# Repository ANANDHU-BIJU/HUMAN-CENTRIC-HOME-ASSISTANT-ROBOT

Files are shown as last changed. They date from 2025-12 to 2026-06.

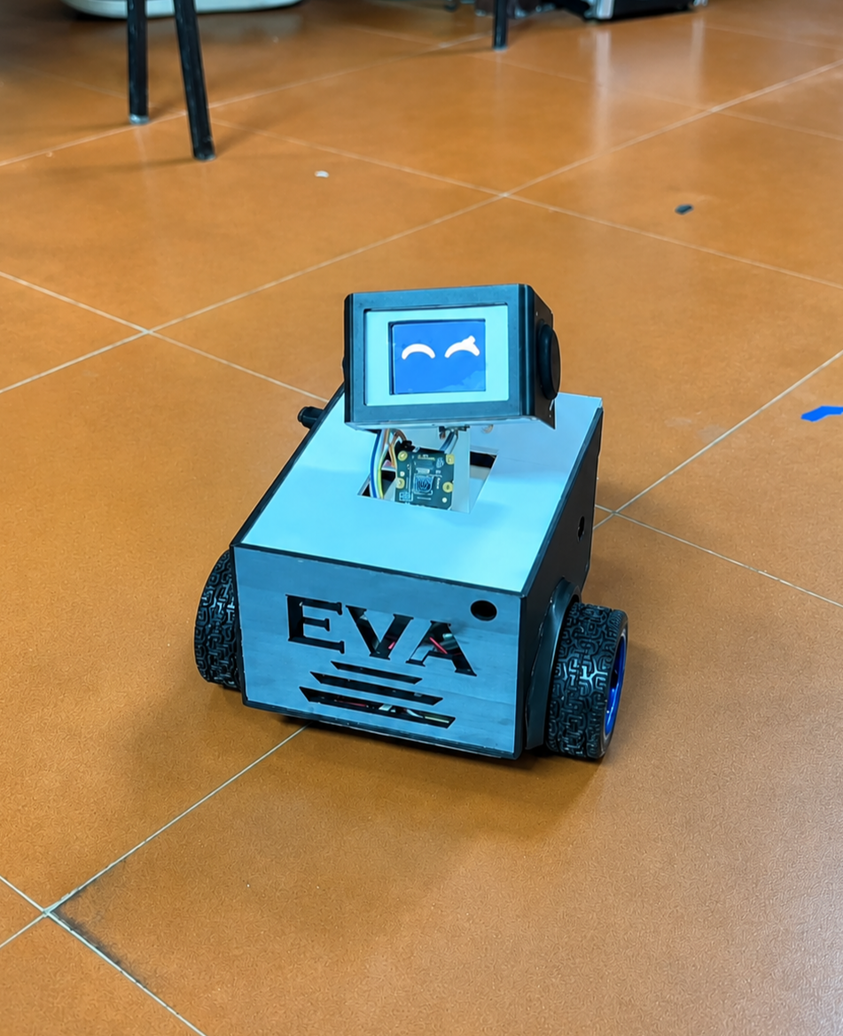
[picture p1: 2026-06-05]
HUMAN_CENTRIC_EMBODIED_HOME_ASSISTANT.png

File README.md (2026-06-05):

# EVA — Human Centered Embodied Home Assistant 🤖

> Voice-activated home assistant robot with face recognition, radar presence detection,
> expressive head movement, and smart home automation.
> 
> 🥇 **First Place — INNOVIX, RISE 2026 | FISAT ECE Department**

---

## 🧠 What is EVA?

EVA is a fully functional human-centric home assistant robot built on **Raspberry Pi 2 + ESP32**,
designed to recognize users, navigate to them, and assist through natural voice interaction.

Unlike conventional voice assistants, EVA physically moves to the user, verifies identity
through face recognition, and responds with expressive animations — making interaction
more natural and personal.

---

## ⚙️ System Architecture

```
┌─────────────────────────────────────────┐
│         RASPBERRY PI 2 MODEL B          │
│  Face Recognition · Voice · Navigation  │
│  Intent Engine · Flask Web UI · Groq AI │
└──────────────┬──────────────────────────┘
               │ HTTP (WiFi)
┌──────────────▼──────────────────────────┐
│              ESP32 WROOM-32             │
│  Motors · Servos · TFT · Radar · Face  │
└──────────────────────────────────────────┘
               │ HTTP (WiFi)
┌──────────────▼──────────────────────────┐
│            ESP8266 NodeMCU              │
│     Garden Relay · Light Control        │
└──────────────────────────────────────────┘
```

---

## 🔧 Features

| Feature | Details |
|---|---|
| 🎙️ Wake Word | Porcupine — "Hey Eva" |
| 👁️ Face Recognition | OpenCV — Haar + LBPH |
| 📡 Presence Detection | LD2410 mmWave Radar |
| 😊 Face Display | ST7735R TFT — 6 bitmap expressions |
| 🤖 3-DoF Head | MG90S servos — Yaw · Pitch · Roll |
| 🚗 Navigation | TB6612FNG + N25 gear motors |
| 🏠 Home Automation | ESP8266 relay — pump + lights |
| 🧠 AI Conversation | Groq LLM (Llama 3) |
| 🌐 Web UI | Flask dashboard — auth + controls |
| 🔌 Custom PCB | KiCad 9.0.5 — full system integration |
| 🖨️ Body | 3D printed enclosure (PLA) |

---

## 🛠️ Hardware

- Raspberry Pi 2 Model B
- ESP32 WROOM-32 DevKit
- ESP8266 NodeMCU
- Pi Camera Module V2 (NoIR)
- ST7735R TFT Display
- HLK-LD24 mmWave Radar
- TB6612FNG Motor Driver
- N25 Metal Gear Motors × 2
- MG90S Servo Motors × 3
- PAM8403 Audio Amplifier
- Custom PCB (KiCad 9.0.5)
- 2S Li-ion Battery (7.4V)

---

## 💻 Software Stack

```python
stack = {
    "Pi"      : ["Python 3", "OpenCV", "Porcupine", "Flask",
                 "edge-TTS", "Google STT", "Groq LLM"],
    "ESP32"   : ["Arduino C++", "WebServer", "SPI", "LEDC PWM"],
    "ESP8266" : ["Arduino C++", "ESP8266WebServer"],
    "PCB"     : ["KiCad 9.0.5"],
    "Body"    : ["Fusion 360", "3D Printing (PLA)"],
}
```

---

## 📬 Contact




---

<p align="center"><i>Built with curiosity. Powered by embedded silicon. Driven by the need to build things that actually work.</i></p>

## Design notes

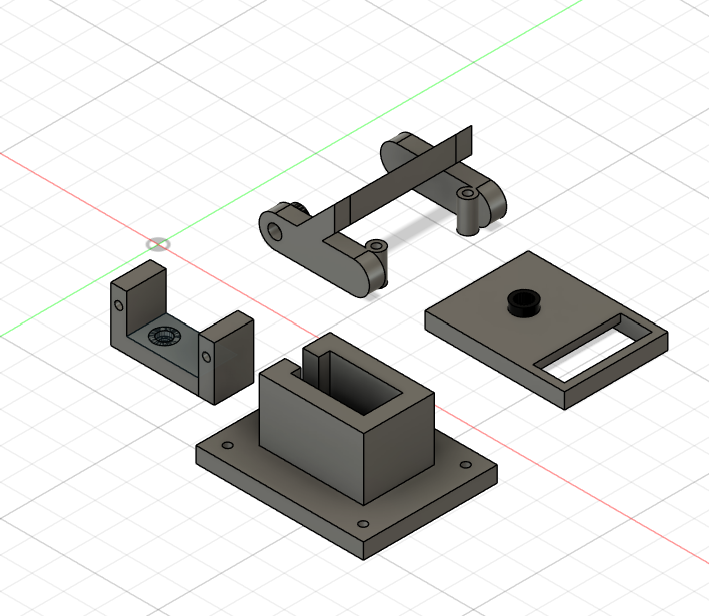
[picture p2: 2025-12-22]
mechanical/renders/exploded_view.png

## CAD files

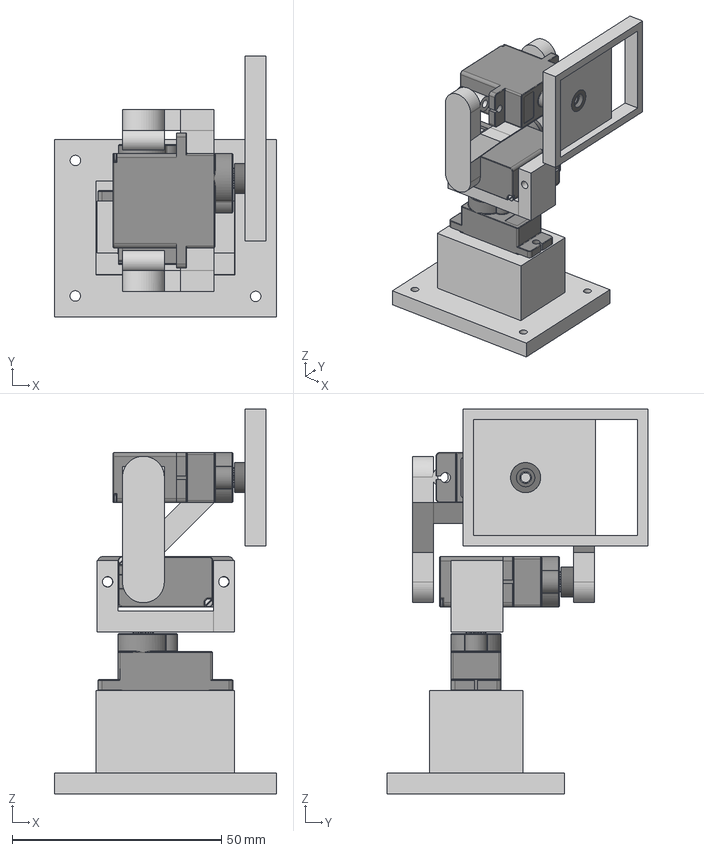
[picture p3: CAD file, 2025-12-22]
mechanical/assembly/head_assembly_v1.step
53.1 x 62.3 x 92.0 mm
Shaft x 3
Horn x 3
Screw x 3

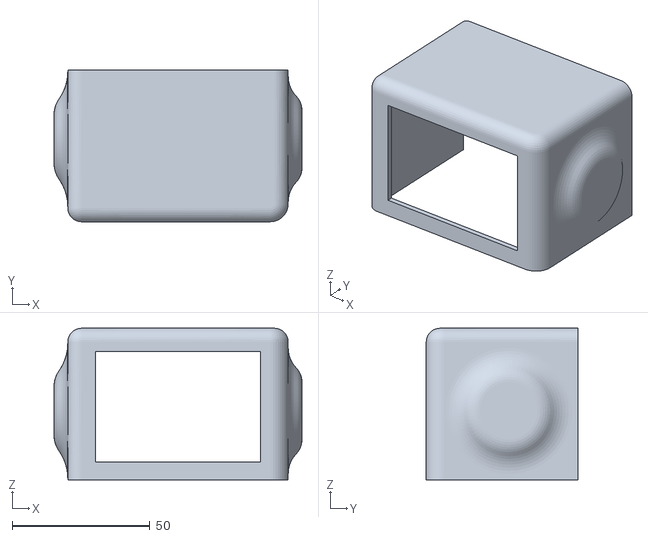
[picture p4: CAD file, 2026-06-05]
mechanical/parts/EVA_HEAD_COVER.stl
90.0 x 55.0 x 55.0

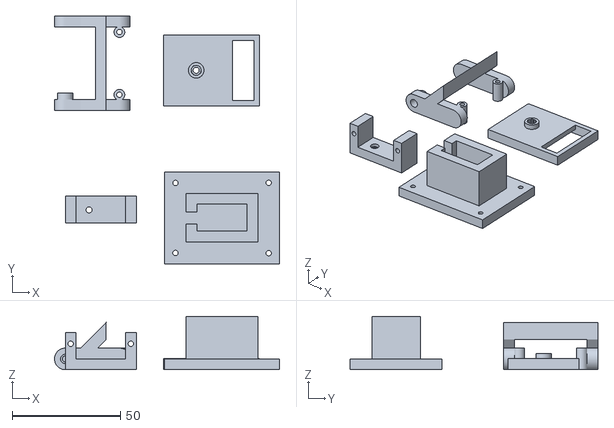
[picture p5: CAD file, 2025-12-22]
mechanical/assembly/exploded_view_v1.stl
104.0 x 114.4 x 24.7

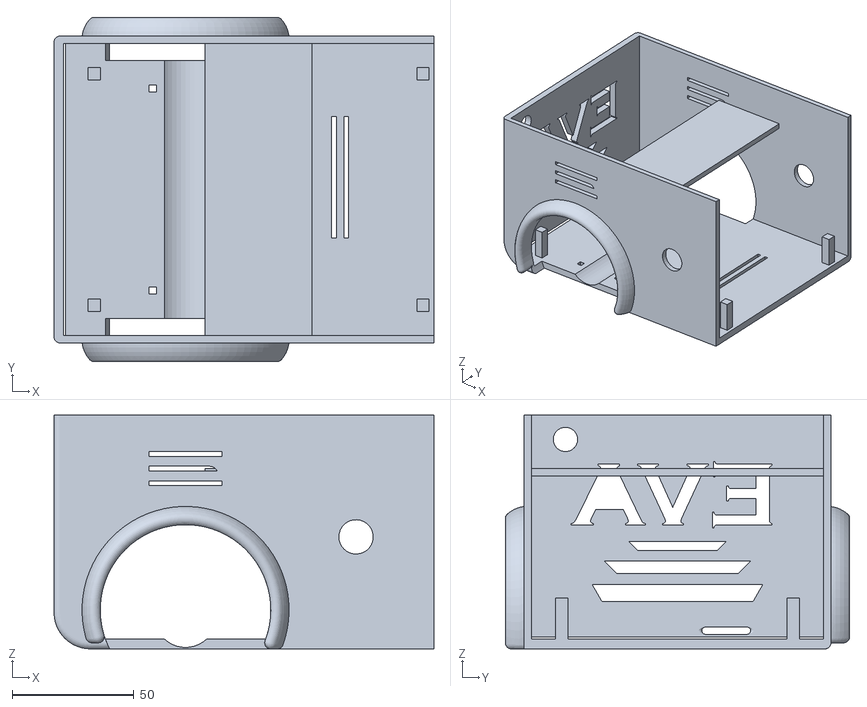
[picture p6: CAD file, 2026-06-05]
mechanical/parts/EVA_BODY.stl
156.0 x 141.4 x 96.0

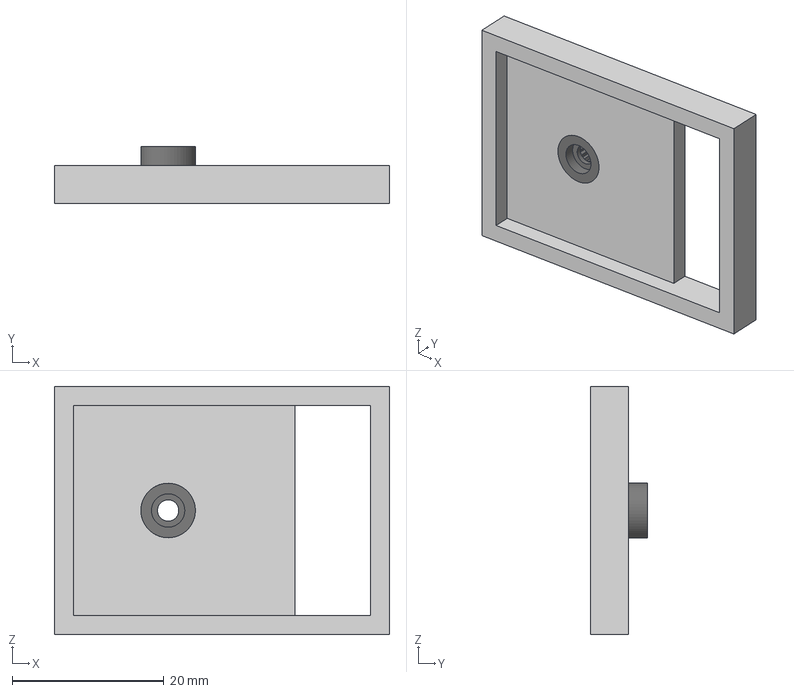
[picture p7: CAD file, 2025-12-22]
mechanical/parts/roll_mount_v1.step
44.2 x 7.50 x 32.8 mm
Shaft
Horn
Screw

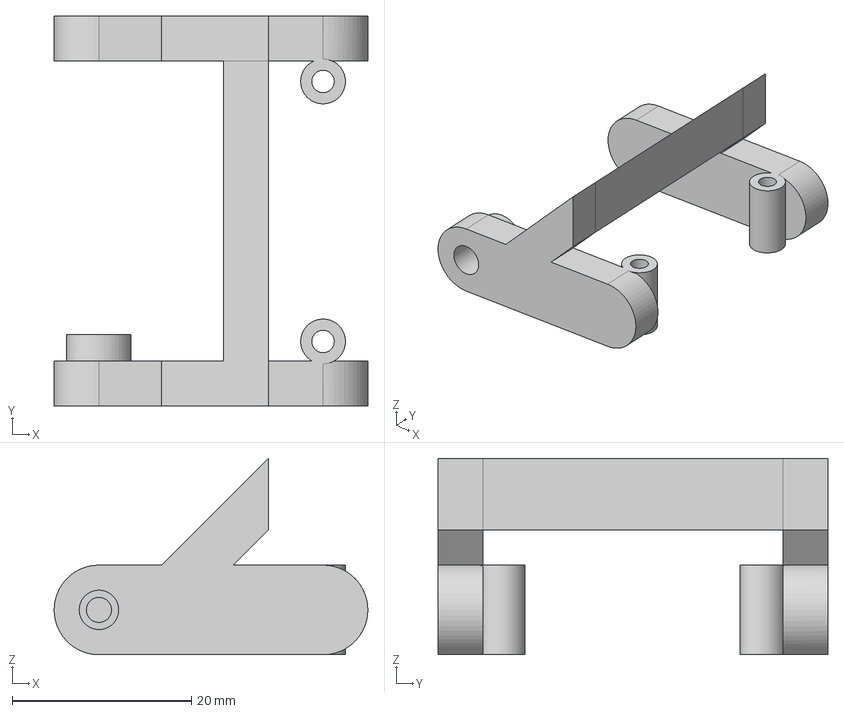
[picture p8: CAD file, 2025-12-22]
mechanical/parts/pitch_mount_v1.step
35.0 x 43.5 x 21.9 mm
Shaft
Horn
Screw

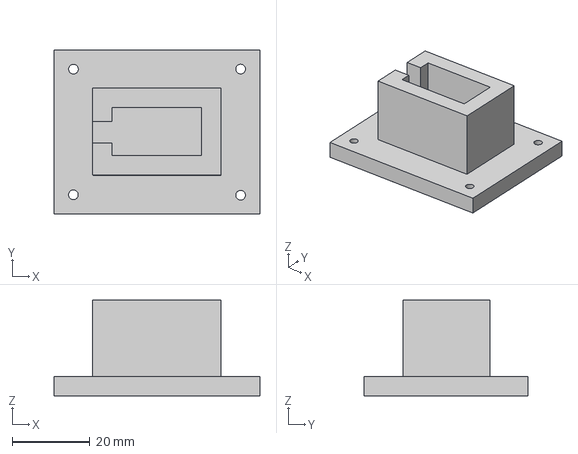
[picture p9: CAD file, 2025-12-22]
mechanical/parts/base_mount_v1.step
53.1 x 42.4 x 24.7 mm

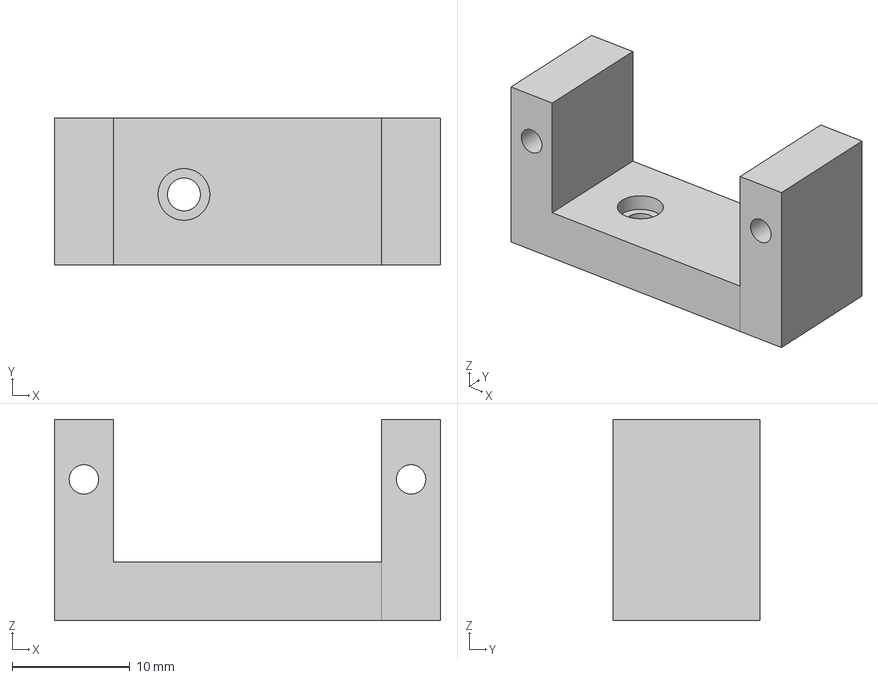
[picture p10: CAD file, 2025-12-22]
mechanical/parts/yaw_mount_v1.step
32.8 x 12.5 x 17.1 mm
Shaft
Horn
Screw

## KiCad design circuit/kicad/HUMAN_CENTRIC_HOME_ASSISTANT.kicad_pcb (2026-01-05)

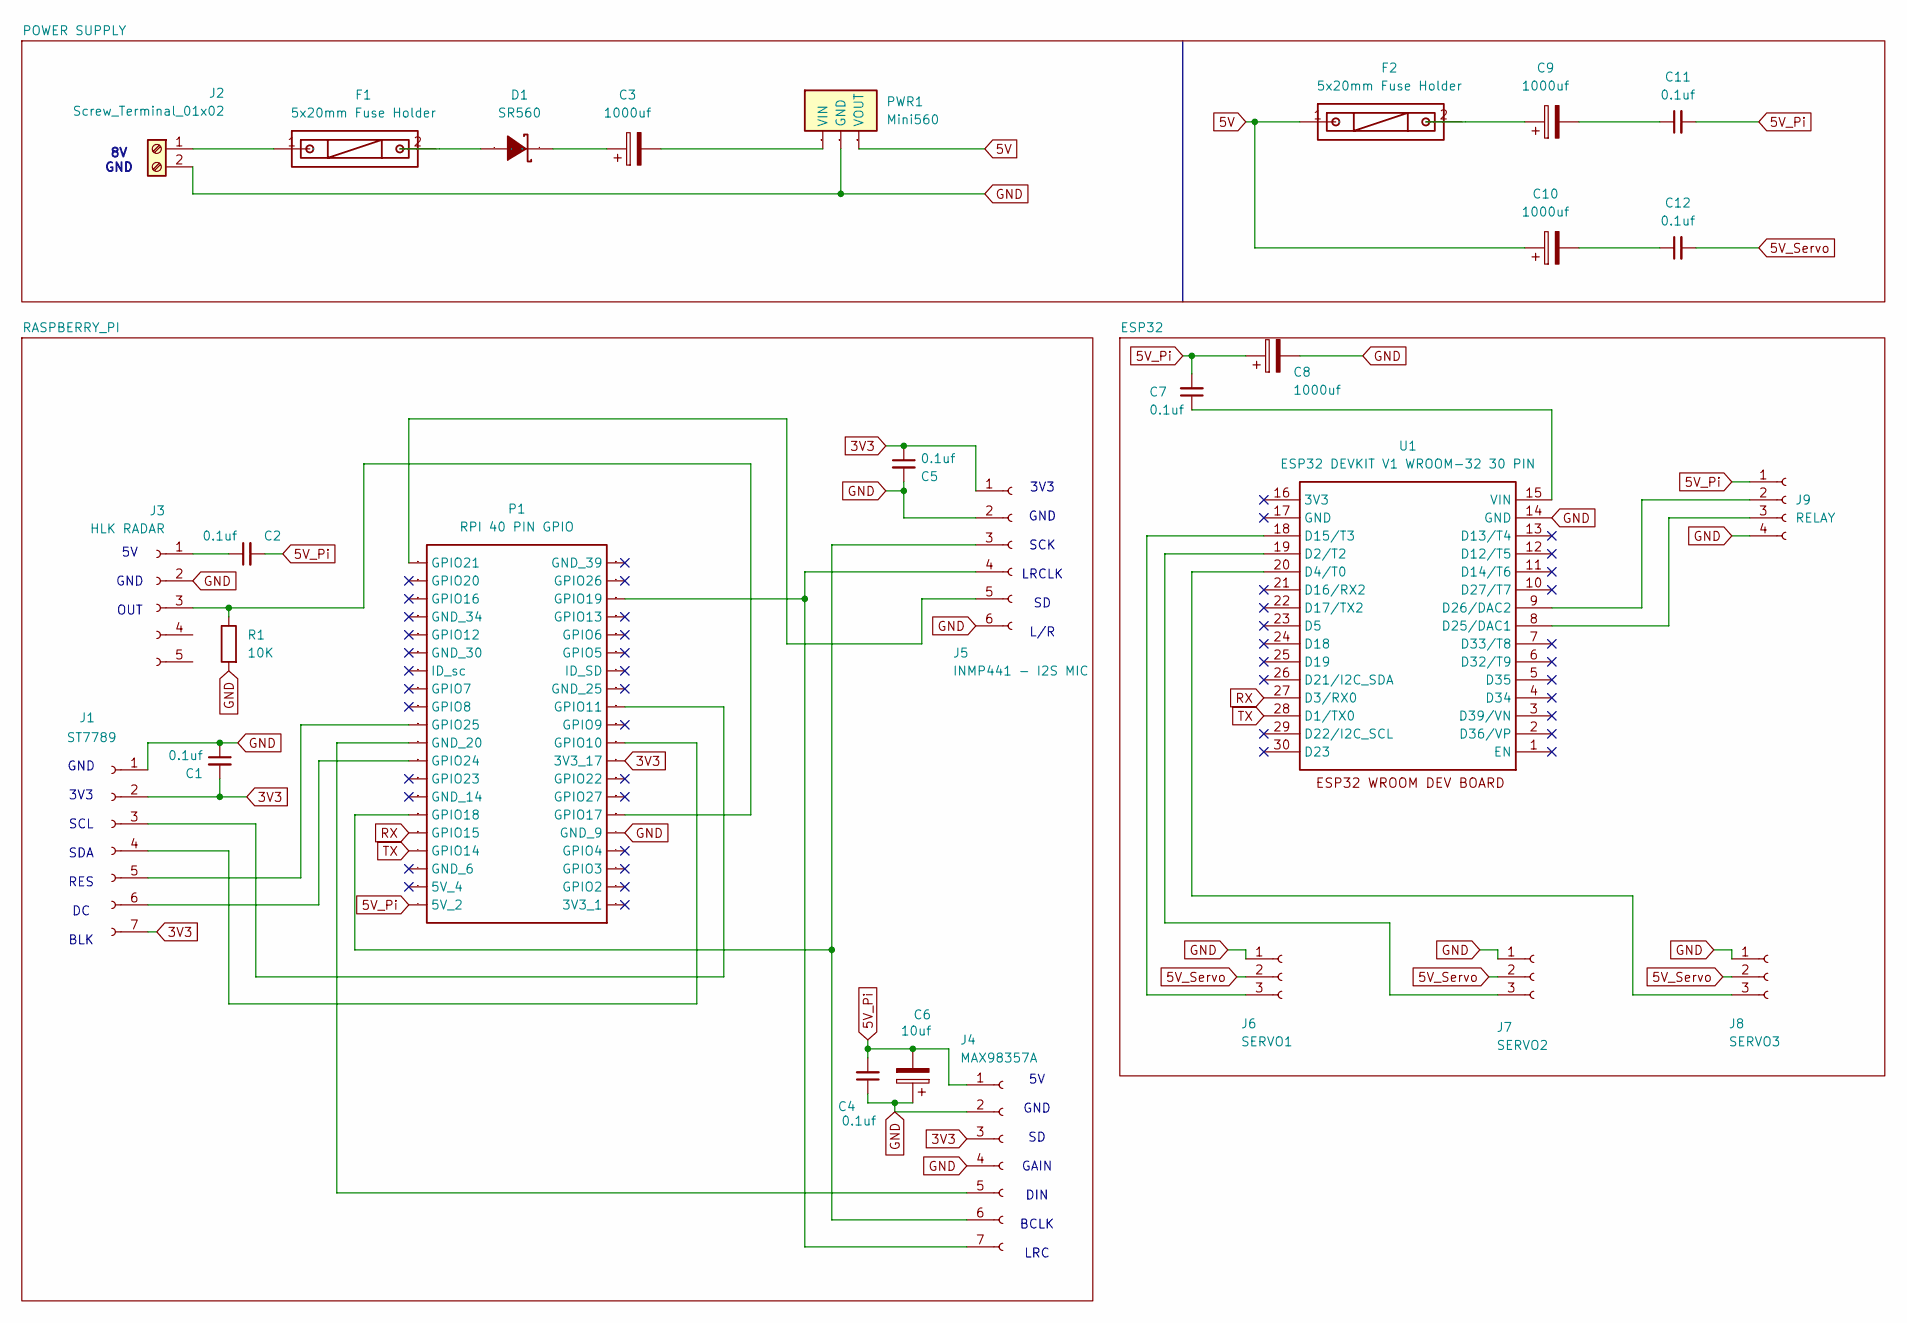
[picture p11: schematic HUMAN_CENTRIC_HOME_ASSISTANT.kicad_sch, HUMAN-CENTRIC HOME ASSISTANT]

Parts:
C1, C2, C4, C5, C7, C11, C12: 0.1uf; C_Disc_D5.0mm_W2.5mm_P5.00mm
C3, C8, C9, C10: 1000uf; CP_Radial_D10.0mm_P5.00mm
C6: 10uf; CP_Radial_D6.3mm_P2.50mm
D1: SR560; SR560 Schottky Barrier Rectifier Diode 5A; Manufacturer Part SR560
F1, F2: 5x20mm Fuse Holder; 5X20-FUSE
J1: ST7789; PINHEADER_1X07_P2.54MM_VERTICAL
J2: Screw_Terminal_01x02; SCREWTERMINAL-5MM-2-DW
J3: HLK RADAR; PINHEADER_1X05_P2.54MM_VERTICAL
J4: MAX98357A; PINHEADER_1X07_P2.54MM_VERTICAL
J5: INMP441 - I2S MIC; CONNECTOR_PINHEADER_2.54MMPINHEADER_1X06_P2.54MM_VERTICAL
J6: SERVO1; CONN-HEADER-STRAIGHT-P2.54MM-1X03
J7: SERVO2; CONN-HEADER-STRAIGHT-P2.54MM-1X03
J8: SERVO3; CONN-HEADER-STRAIGHT-P2.54MM-1X03
J9: RELAY; PINSOCKET_1X04_P2.54MM_VERTICAL
P1: RPI 40 PIN GPIO; 2X20-PIN-HEADER
PWR1: Mini560; MINI560; Manufacturer Part mini560
R1: 10K; R_Axial_DIN0207_L6.3mm_D2.5mm_P7.62mm_Horizontal
U1: ESP32 DEVKIT V1 WROOM-32 30 PIN; ESP32 DEVKIT V1 30 PIN

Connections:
3V3: C1.2, C5.1, J1.2, J1.7, J4.3, J5.1, P1.17 (3V3_17)
5V: C10.1, F2.1, PWR1.VOUT
5V_Pi: C2.2, C4.2, C6.2, C7.2, C8.1, C11.2, J4.1, J9.1, P1.2 (5V_2)
5V_Servo: C12.2, J6.2, J7.2, J8.2
GND: C1.1, C4.1, C5.2, C6.1, C8.2, J1.1, J2.2, J3.2, J4.2, J4.4, J5.2, J5.6, J6.1, J7.1, J8.1, J9.4, P1.9 (GND_9), PWR1.GND, R1.1, U1.14 (GND)
unnamed: C3.2, PWR1.VIN
unnamed: C9.1, F2.2
unnamed: C10.2, C12.1
unnamed: C9.2, C11.1
unnamed: D1.1 (A), F1.2
unnamed: C3.1, D1.2 (K)
unnamed: J1.3, P1.23 (GPIO11)
unnamed: J1.4, P1.19 (GPIO10)
unnamed: J1.5, P1.22 (GPIO25)
unnamed: J1.6, P1.18 (GPIO24)
unnamed: F1.1, J2.1
unnamed: C2.1, J3.1
unnamed: J3.3, P1.11 (GPIO17), R1.2
unnamed: J4.5, P1.20 (GND_20)
unnamed: J4.6, J5.3, P1.12 (GPIO18)
unnamed: J4.7, J5.4, P1.35 (GPIO19)
unnamed: J5.5, P1.40 (GPIO21)
unnamed: J6.3, U1.18 (D15/T3)
unnamed: J7.3, U1.19 (D2/T2)
unnamed: J8.3, U1.20 (D4/T0)
unnamed: J9.2, U1.9 (D26/DAC2)
unnamed: J9.3, U1.8 (D25/DAC1)
unnamed: C7.1, U1.15 (VIN)
RX: P1.10 (GPIO15), U1.27 (D3/RX0)
TX: P1.8 (GPIO14), U1.28 (D1/TX0)

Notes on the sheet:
8V GND
3V3 GND SCK LRCLK SD L/R
GND 3V3 SCL SDA RES DC BLK
5V GND SD GAIN DIN BCLK LRC
5V GND OUT

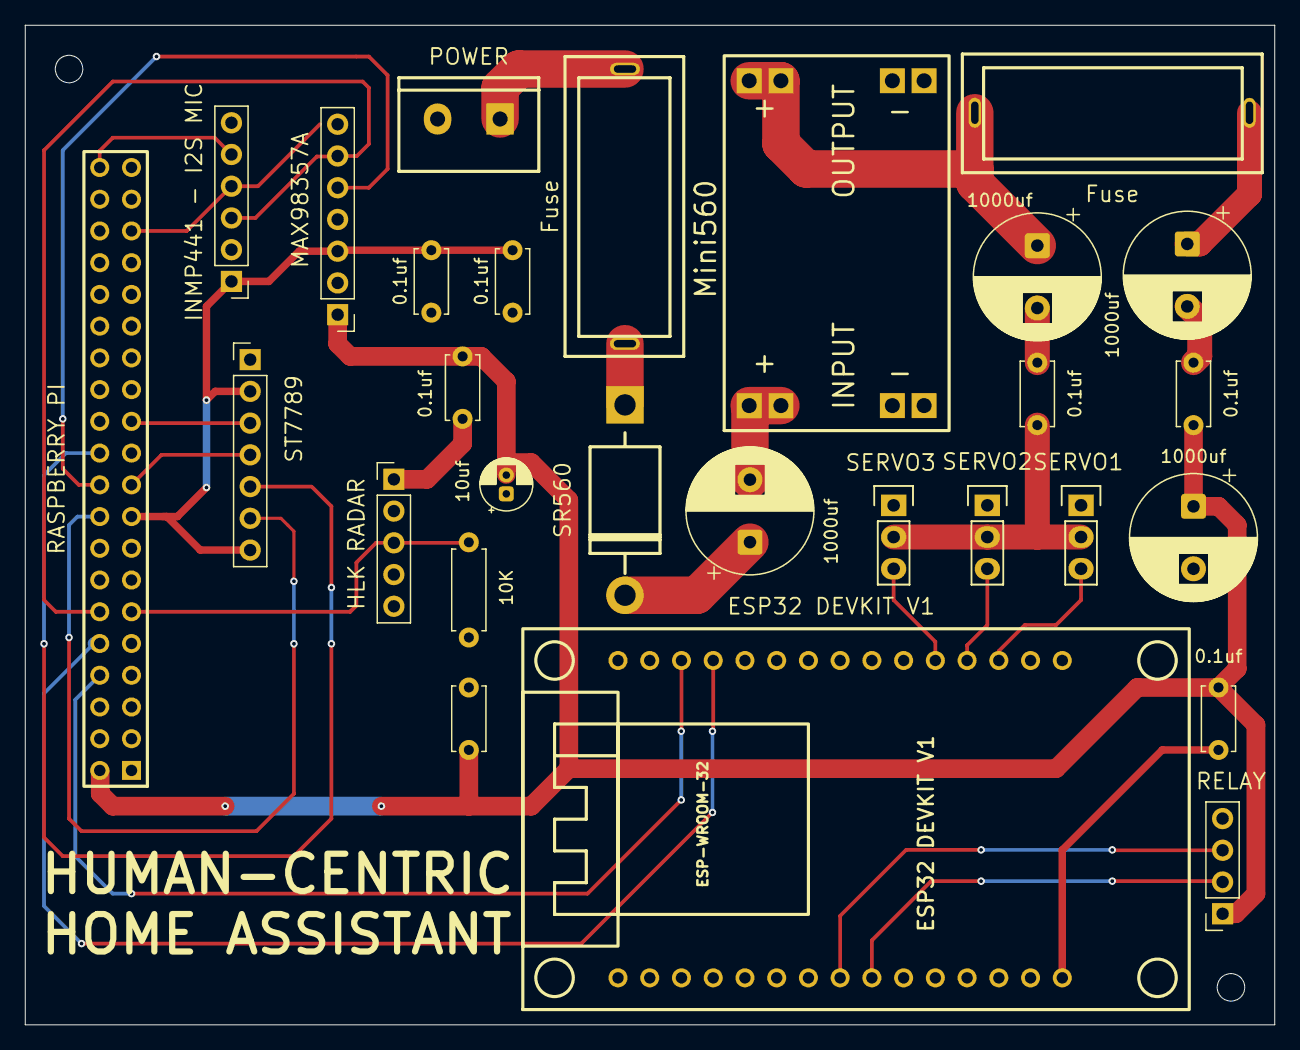
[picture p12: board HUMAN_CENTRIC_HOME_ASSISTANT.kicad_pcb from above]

Board: 2 copper layers, 100.0 x 80.0 mm, 28 parts (0 on the bottom side), 30 nets.

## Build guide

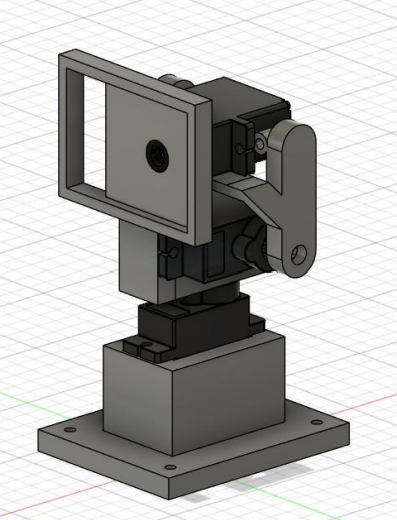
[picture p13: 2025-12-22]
mechanical/renders/assembled_view.png

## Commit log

2025-12-22 clarify project scope and current development phase
2025-12-22 remove old mechanical files for cleanup
    [All_4.step, All__4.stl, DISPLAY.step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]
2025-12-22 add exploded and assembled render views
2025-12-22 add mechanical assembly and parts folders
2025-12-25 add kicad files
2025-12-25 Update circuit README
2025-12-25 create folder for kicad files
2025-12-25 add zip file of kicad pcb design
2025-12-25 add gerber file of pcb
2025-12-25 add .zip gerber file
2025-12-25 Remove archived KiCad PCB files
2025-12-25 Remove archived gerber
2026-01-05 Create folder for circuit pdf
2026-06-05 ``` Complete EVA project README — add features, architecture, hardware, and software stack ```
2026-06-05 Revise README for EVA Human Centered Home Assistant Circuit
2026-06-05 Update Eva Head and body stl files
    [EVA_BODY.stl, EVA_HEAD_COVER.stl]
